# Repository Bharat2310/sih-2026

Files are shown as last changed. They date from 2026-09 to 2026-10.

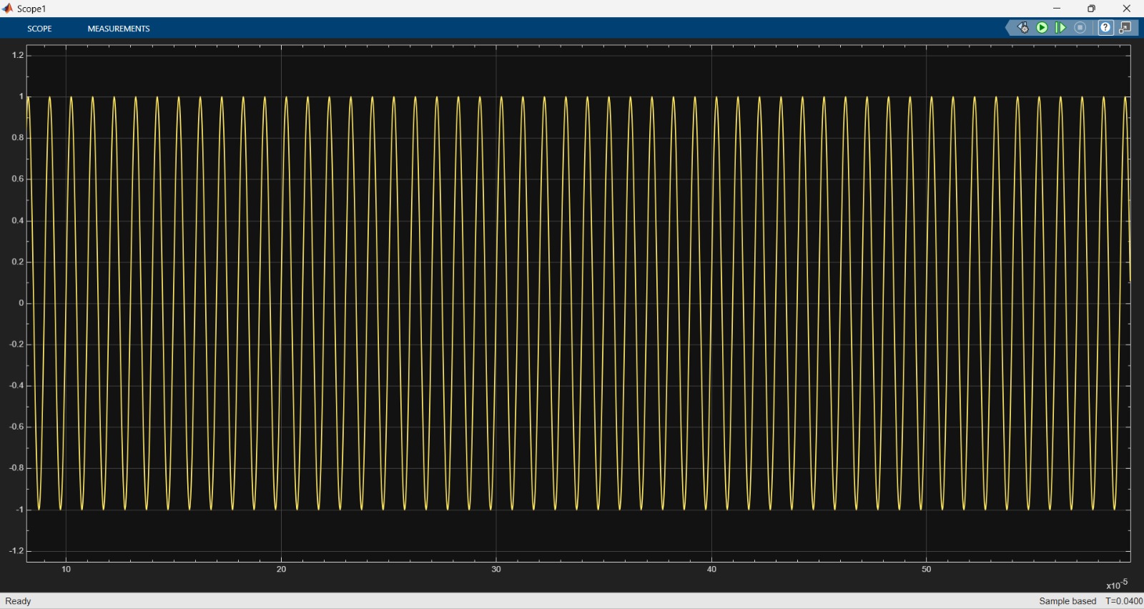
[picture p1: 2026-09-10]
assets/screenshots/mode1_geometricsweep_final.jpeg

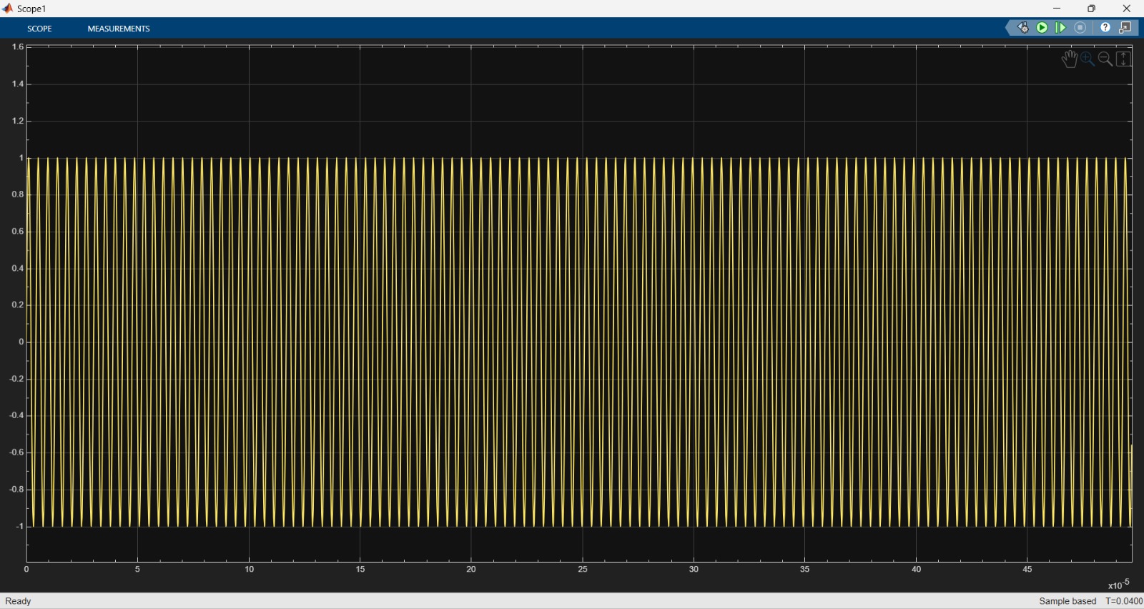
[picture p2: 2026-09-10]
assets/screenshots/mode1_geometricsweep_raw.jpeg

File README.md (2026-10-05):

# Adaptive Underwater Sonar Transmitter for AUVs

## 1. Project Information

- **Project Title:** Adaptive Software-Defined Sonar Transmitter for AUVs
- **PS ID:** 26058
- **PS Title:** Development of a Low-Power, Real-Time Adaptive Software-Defined Sonar Transmitter Payload for Autonomous Underwater Vehicles (AUVs)
- **Category:** Hardware
- **Theme:** Robotics and Drones

## 2. Problem Statement

Fixed-frequency sonar transmitters used in Autonomous Underwater Vehicles (AUVs) perform poorly when water conditions change. High turbidity, varying depth and temperature gradients all affect how sound propagates underwater, causing loss of resolution, weak returns, or complete signal degradation. A sonar system tuned for clear, shallow water fails in turbid or deep-water conditions, and vice versa,  there is no single fixed frequency/pulse configuration that works well everywhere.

## 3. Proposed Solution

We propose a **Software-Defined Sonar (SDS)** transmitter that adapts its waveform in real time based on sensed water conditions, instead of using a single fixed frequency.

The system continuously reads **turbidity**, **depth**, and **temperature** via ADC channels (mapped from potentiometer inputs at the current prototype stage) and uses this data to dynamically determine the most suitable suitable transmission configuration and parameters.

**ADAPTIVE WAVEFORM AND PARAMETER SELECTION**

- **Center frequency** (500 kHz / 250 kHz / 100 kHz) based on turbidity band — turbidity limits the base frequency band to prevent signal scattering
- **Pulse width (T_pulse)** (1 ms / 10 ms / 50 ms) based on depth band — depth dictates total pulse duration for deeper energy penetration
- **Modulation type** — automatically decided by the Mod_Select Decision Block, not manually selected:
         1. heavy silt (turbidity_voltage > 2.4V) forces Barker-13 phase-coded pulse 
         2. deep water (depth_m > 30) forces Geometric Sweep (Mode 1)
         3. standard conditions default to LFM Chirp (Mode 0)
- **Sound velocity correction** using the Mackenzie (1981) formula, recalculated continuously from real-time temperature and fed directly into bandwidth correction every cycle
- **Bandwidth** dynamically compensated to maintain a target 2 cm range resolution (dR_target) across the operating frequency bands, eliminating the need for manual reconfiguration even at the 100 kHz operating point.

**DIGITAL WAVEFORM GENERATION AND LOW POWER TRANSMISSION**

The selected waveform is synthesized digitally by the ESP32. During the 5 ms TX window, the CPU computes a 100-sample waveform array corresponding to the required modulation, frequency, bandwidth and pulse duration.
The waveform then passes through mode-dependent digital windowing:
1. Blackman window for LFM chirps and geometric sweeps to control sidelobes and reduce spectral leakage
2. Rectangular/light Tukey window for Barker-13 phase-coded pulses, where preserving the individual phase-coded chips is important.

Once the waveform is prepared, the ESP32 arms a hardware timer and DMA transfer. The DMA autonomously transfers the 100 samples from RAM to the DAC at a 200 kHz sample rate, corresponding to a 5 μs Zero-Order Hold (ZOH) interval. This allows the CPU to immediately enter Light Sleep instead of continuously driving the DAC in software.
When the DMA transfer finishes, a hardware interrupt wakes the CPU briefly. The CPU shuts down the DAC to prevent unnecessary static power consumption and then returns to sleep during the remaining LISTEN period.
This creates a time-shared TX/LISTEN cycle, allowing the same transducer path to be used for transmission and reception without simultaneous TX/RX conflict.

**ANALOG SIGNAL CONDITIONING AND POWER DELIVERY**

After digital synthesis and DAC conversion, the waveform becomes a low-voltage (~3.3 V) analog signal. This signal is then processed by analog front end to clean, amplify, and efficiently couple it to the piezoelectric sonar transducer.

Analog chain: 
1. Signal Routing: CD4051 Analog MUX
The CD4051 MUX routes the waveform to one of three dedicated Clear, Murky, or Muddy filter paths based on the environmental condition provided by the ESP32.
2. Signal Conditioning: LT1058 Filter
The selected path uses an LT1058 Sallen-Key 2nd-order Butterworth low-pass filter with a condition-specific cutoff frequency. It removes unwanted high-frequency switching noise and harmonics, producing a cleaner ~3.3 V waveform.
3. Power Amplification: LM318N + Class-AB Stage
The filtered signal is amplified using an LM318N driver with a 7.2× feedback gain, followed by a Class-AB BD139/BD140 push-pull stage powered from 18 V rails. This provides the high-voltage, high-current drive required by the transducer, targeting approximately 24 Vpp output.
4. Impedance Matching: LC Network
Since the piezoelectric transducer behaves predominantly as a capacitive load, the LC network uses an inductive component to compensate for its capacitive reactance, improve electrical resonance, and enable more efficient power transfer.
5. Acoustic Transmission: Piezoelectric Transducer
The matched high-voltage waveform is applied to the piezoelectric transducer, which converts the electrical excitation into mechanical vibration and generates the acoustic sonar pulse in water.

This completes the transmitter-side signal chain, with the transducer converting the conditioned electrical waveform into the acoustic sonar pulse for underwater transmission.

## 4. Key Features

- **Real-Time Environmental Adaptation:** Dynamically adapts waveform parameters using turbidity, depth, and temperature.
- **Adaptive 100–500 kHz Operation:** Shifts frequency according to turbidity to reduce scattering.
- **Consistent 2 cm Resolution:** Dynamically compensates bandwidth across operating frequencies.
- **3-Mode Waveform Selection:** Automatically switches between LFM Chirp, Geometric Sweep, and Barker-13 Phase Coding.
- **Temperature-Based Correction:** Continuously calculates acoustic velocity for accurate bandwidth control.
- **Dual-Stage Signal Conditioning:** Combines digital windowing with dedicated analog filtering to reduce sidelobes, noise, and harmonics.
- **DMA-Based Low-Power Operation:** Uses hardware-timed DMA waveform output with a 5 ms TX / 15 ms LISTEN cycle.
- **Impedance-Matched Transducer Drive:** Uses amplification and LC matching for efficient power transfer to the piezoelectric transducer.

## 5. Technology Stack

- **Simulation / Signal Design:** MATLAB R2026a (Simulink, DSP System Toolbox), LTSpice 
- **Embedded Firmware:** ESP32 (C, hardware timers, ISR-driven waveform synthesis, DMA)
- **DAC (Phase 2 hardware):** MCP4921 (SPI)
- **Analog Front End:** CD4051 analog MUX, LT1058 Sallen-Key active filters, LM318N / Class-AB power amplifier, LC impedance matching network
- **Version Control:** Git / GitHub

## 6. Architecture

The system follows an adaptive digital-to-analog signal chain in which environmental inputs determine the transmission frequency, pulse duration, sound-velocity correction, and modulation mode. 
```
Turbidity ADC ─┐
Depth ADC ─────┼──> Decision Logic + Mod_Select Decision Block
Temperature ───┘                    │
                                    ▼
                 Center Freq, T_pulse, Sound Velocity,
                         Bandwidth, Mode (0/1/2)
                                    │
                                    ▼
                       Modulation Selector
                  ┌─────────────────────────────┐
                  │ Mode 0: LFM Chirp           │
                  │ Mode 1: Geometric Sweep     │
                  │ Mode 2: Barker-13           │
                  └─────────────────────────────┘
                                    │
                                    ▼
                       Conditional Windowing
                       (Blackman / Tukey)
                                    │
                                    ▼
                       TX/LISTEN Pulse Gating
                         (0.02 s, 25% duty)
                                    │
                                    ▼
                        Buffer (100) → Unbuffer
                                    │
                                    ▼
                         ZOH (5 μs / 200 kHz)
                                    │
                                    ▼
                                  DAC
                                    │
                                    ▼
                         3.3 V Analog Signal
                                    │
                                    ▼
                         CD4051 Analog MUX
                                    │
                                    ▼
                      Sallen-Key Active Filter
                                    │
                                    ▼
                    LM318N + Class-AB Amplifier
                              (~24 Vpp)
                                    │
                                    ▼
                       LC Impedance Matching
                                    │
                                    ▼
                      Piezoelectric Transducer
```

## 7. Repository Structure

```
sih-2026/
├── README.md
├── submission/
│   ├── PRESENTATION.md      # link to final PPT
│   └── DEMO.md              # link to prototype demo video
├── src/
│   ├── simulink/
│   │   └── before_dac_model.slx     # digital pipeline (Decision Logic -> ... -> ZOH -> DAC)
│   ├── esp32-firmware/
│   │   └── esp32-firmware.ino       # ESP32 firmware (tested build)
│   └── ltspice/
│       ├── after_dac_model.asc      # analog front-end circuit (after DAC)
│       └── working_analog.asc       # working analog reference circuit
├── docs/
│   └── architecture.md
├── assets/
│   └── screenshots/
        ├── after_dac_schematic.jpeg
│       ├── after_dac_waveform.jpeg
│       ├── before_dac_full_pipeline.png
│       ├── decision_logic.jpeg
│       ├── mod_select_decision.jpeg
│       ├── modulation_selector.jpeg
│       ├── mode0_lfm_final.jpeg
│       ├── mode0_lfm_raw.jpeg
│       ├── mode1_geometricalsweep_final.jpeg
│       ├── mode1_geometricalsweep_raw.jpeg
│       ├── mode2_phasecoded_final.jpeg
│       └── mode2_phasecoded_raw.jpeg
│       ├── future_scope_schematic.jpeg
│       └── README.md
├── .gitignore
└── LICENSE
```

## 8. Final Presentation

[View the Final Presentation](submission/PRESENTATION.md)

## 9. Demo Video

[View the Prototype Demo](submission/DEMO.md)

## 10. Screenshots / Prototype Photos

Simulink model screenshots, waveform captures, decision-logic results and analog front-end/prototype images are available in: [assets/screenshots/README.md](assets/screenshots/README.md) 

## 11. Installation

Clone the repository and install the required dependencies:
```
bash
git clone https://github.com/Bharat2310/sih-2026.git
cd sih-2026
```

Prerequisites
1. MATLAB R2026a with Simulink and DSP System Toolbox
2. LTspice
3. Arduino IDE or PlatformIO for ESP32 firmware

## 12. Run

- **Before-DAC Simulink model:** Open `src/simulink/before_dac_model.slx` in MATLAB R2026a and run. Remember to redefine the Blackman window variable in the Command Window after every MATLAB restart:
  ```matlab
  N=100; n=(0:N-1)'; w=0.42-0.5*cos(2*pi*n/(N-1))+0.08*cos(4*pi*n/(N-1));
  ```
- **After-DAC analog front-end model:** Open `src/ltspice/after_dac_model.asc` in LTSpice and run.
- **ESP32 firmware:** Open `src/esp32-firmware/esp32-firmware.ino` in Arduino IDE or PlatformIO, select the appropriate ESP32 board and port then compile and uplaod.
  
## 13. Future Scope

- **Higher-Rate ZOH:** Increase the ZOH sample rate from 200 kHz to ≥1.25 MHz to support the 500 kHz operating band without Nyquist violation
- **Ping-Pong Buffering:** Dual-buffer DMA scheme so the CPU synthesizes the next 100-sample frame while DMA transmits the current one, minimizing CPU active time with zero inter-frame latency/jitter (trade-off: doubles RAM footprint). Planned refinement: hardware-level automatic buffer-pointer swap on DMA interrupt.
- **Fixed-Point DSP:** Replace floating-point calculations with Q15 arithmetic and SRAM lookup tables for faster, low-overhead waveform generation.
- **ADC Hysteresis & Deadbanding (EMA filtering):** Smooths turbidity/temperature ADC reads so the system reacts to real environmental trends instead of chattering between modes around hard thresholds (e.g. 2.4V turbidity), at the cost of slight reaction lag. Planned refinement: bit-shifting EMA calculations instead of division to remove CPU overhead.
- **Dynamic Voltage Scaling:** Dynamically adjust the amplifier supply from approximately 9 V to 24 V according to environmental conditions, with up to 40% projected battery-life improvement.
- **High-Slew Analog Drive:** Use high-slew-rate op-amps with appropriate windowing to reliably support phase-coded waveforms such as Barker-13.

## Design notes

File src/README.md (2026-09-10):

```
src/
├── simulink/
│   ├── before_dac_model.slx   # digital chirp pipeline (before DAC)
│   └── .gitkeep
├── esp32-firmware/
│   ├── esp32-firmware.ino     # ESP32 firmware (tested build)
│   └── .gitkeep
└── ltspice/
    ├── after_dac_model.asc    # analog front-end circuit (after DAC)
    └── working_analog.asc     # working analog reference circuit
```

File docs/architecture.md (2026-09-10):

# Adaptive Software-Defined Sonar Transmitter

## 1. Overview

The transmitter adapts its waveform in real time based on sensed water conditions (turbidity, depth, temperature) instead of relying on a single fixed frequency/pulse configuration. The architecture is split into two halves that map directly onto the two Simulink models in this repo:

- **Digital pipeline (pre-DAC)** — `src/simulink/before_dac_model.slx`: sensing → decision logic → waveform synthesis → windowing → buffering → DAC.
- **Analog front end (post-DAC)** — `src/ltspice/after_dac_model.asc`: DAC output → filtering → amplification → impedance matching → transducer.

The ESP32 (`src/esp32-firmware/`) is the bridge between the two: it runs the decision logic and digital synthesis in firmware, then drives the analog chain via the DAC and MUX control lines.

## 2. Full Signal Chain

```
Turbidity ADC ─┐
Depth ADC ─────┼──> Decision Logic + Mod_Select Decision Block
Temperature ───┘                    │
                                     ▼
                  Center Freq, T_pulse, Sound Velocity,
                          Bandwidth, Mode (0/1/2)
                                     │
                                     ▼
                        Modulation Selector
                   ┌─────────────────────────────┐
                   │ Mode 0: LFM Chirp            │
                   │ Mode 1: Geometric Sweep       │
                   │ Mode 2: Barker-13             │
                   └─────────────────────────────┘
                                     │
                                     ▼
                        Conditional Windowing
                        (Blackman / Tukey)
                                     │
                                     ▼
                        TX/LISTEN Pulse Gating
                          (0.02 s cycle, 25% duty)
                                     │
                                     ▼
                         Buffer (100) → Unbuffer
                                     │
                                     ▼
                          ZOH (5 µs / 200 kHz)
                                     │
                                     ▼
                                   DAC
                                     │
                                     ▼
                          3.3 V Analog Signal
                                     │
                                     ▼
                          CD4051 Analog MUX
                                     │
                                     ▼
                       Sallen-Key Active Filter
                                     │
                                     ▼
                     LM318M + Class-AB Amplifier
                               (~24 Vpp)
                                     │
                                     ▼
                        LC Impedance Matching
                                     │
                                     ▼
                       Piezoelectric Transducer
```

## 3. Digital Pipeline (Pre-DAC)

**Model:** `src/simulink/before_dac_model.slx`

### 3.1 Sensing
Turbidity, depth, and temperature are read via ADC channels (currently mapped from potentiometer inputs at the prototype stage).

### 3.2 Decision Logic + Mod_Select
Environmental readings are converted into transmission parameters:

| Input | Drives | Effect |
|---|---|---|
| Turbidity | Center frequency band (500 / 250 / 100 kHz) | Limits base frequency to prevent signal scattering |
| Depth | Pulse width T_pulse (1 / 10 / 50 ms) | Longer pulses for deeper energy penetration |
| Temperature | Sound velocity (Mackenzie, 1981) | Recalculated continuously and fed into bandwidth correction every cycle |

The **Mod_Select Decision Block** automatically chooses the modulation mode — not manually selected:
1. Turbidity voltage > 2.4 V → **Mode 2: Barker-13** phase-coded pulse (heavy silt)
2. Depth > 30 m → **Mode 1: Geometric Sweep** (deep water)
3. Otherwise → **Mode 0: LFM Chirp** (standard conditions)

Bandwidth is dynamically compensated to hold a target **2 cm range resolution (dR_target)** across all operating frequency bands, including at 100 kHz.

### 3.3 Digital Waveform Synthesis
During the 5 ms TX window, the ESP32 computes a 100-sample waveform array for the selected modulation, frequency, bandwidth, and pulse duration.

### 3.4 Conditional Windowing
- **Blackman window** — LFM chirps and geometric sweeps, to control sidelobes and reduce spectral leakage.
- **Rectangular / light Tukey window** — Barker-13 pulses, to preserve individual phase-coded chips.

### 3.5 TX/LISTEN Gating, Buffering, ZOH, DAC
- Pulse gating enforces a 0.02 s cycle at 25% duty (5 ms TX / 15 ms LISTEN).
- The 100-sample buffer is unbuffered and output through a Zero-Order Hold at 200 kHz (5 µs interval) via hardware-timed DMA.
- DMA transfers samples from RAM to the DAC autonomously, letting the CPU enter Light Sleep during transmission and wake only on the DMA-finish interrupt to shut down the DAC before sleeping through the remainder of LISTEN.

## 4. Analog Front End (Post-DAC) 

**Model:** `src/ltspice/before_dac_model.asc` 

| Stage | Component | Function |
|---|---|---|
| Signal routing | CD4051 Analog MUX | Routes the waveform to one of three condition-specific paths — Clear / Murky / Muddy |
| Signal conditioning | LT1058 Sallen-Key filter | 2nd-order Butterworth low-pass, condition-specific cutoff, removes switching noise/harmonics |
| Power amplification | LM318M + Class-AB (BD139/BD140) | 7.2× feedback gain driver + push-pull stage on 18 V rails → ~24 Vpp output |
| Impedance matching | LC network | Compensates the transducer's capacitive reactance for efficient power transfer |
| Acoustic transmission | Piezoelectric transducer | Converts the conditioned electrical waveform into the acoustic sonar pulse |

## 5. Key Architectural Features
1. **Real-Time Environmental Adaptation:** Turbidity, depth, and temperature directly influence transmission parameters.
2. **Adaptive Frequency Selection:** Operating frequency shifts between 100 kHz, 250 kHz, and 500 kHz according to turbidity.
3. **Adaptive Pulse Duration:** Pulse duration changes between 1 ms, 10 ms, and 50 ms according to depth.
4. **Dynamic Bandwidth Compensation:** Temperature-based sound velocity correction dynamically determines the required bandwidth.
5. **2 cm Target Resolution:** Bandwidth is calculated using the acoustic range-resolution relationship.
6. **Three Modulation Modes:** LFM Chirp, Geometric Sweep, and Barker-13 Phase Coding.
7. **Digital + Analog Signal Conditioning:** Digital windowing is followed by analog filtering.
8. **TX/LISTEN Operation:** A 5 ms TX window followed by a 15 ms LISTEN window enables time-shared sonar operation.
9. **DMA-Compatible Waveform Streaming:** Buffered waveform generation reduces continuous CPU involvement during transmission.
10. **Efficient Transducer Drive:** Power amplification and LC impedance matching improve energy transfer to the piezoelectric transducer.

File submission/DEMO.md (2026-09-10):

# Demo Video

The prototype demonstration video for Project Poseidon is available at the link below.

## Demo Video Link

[Watch the Prototype Demo](https://drive.google.com/drive/folders/1Pm32NLZ3pSUcfD95rD-MbYwJ-gllIJSA)

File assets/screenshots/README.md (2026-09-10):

## Screenshots

Project development and simulation results are documented through the following screenshots.

### Before-DAC Simulation — Team A

* `before_dac_full_pipeline.png` — Complete Simulink transmitter pipeline before DAC.
* `decision_logic.jpeg` — Environmental parameter-based decision logic.
* `mod_select_decision.jpeg` — Modulation mode selection logic.
* `modulation_selector.jpeg` — Selection between LFM, Geometric Sweep, and Phase-Coded modes.
* `mode_0_lfm_raw.jpeg` — Raw LFM chirp waveform.
* `mode_0_lfm_final.jpeg` — Windowed LFM chirp output.
* `mode_1_geometricsweep_raw.jpeg` — Raw geometric sweep waveform.
* `mode_1_geometricsweep_final.jpeg` — Windowed geometric sweep output.
* `mode_2_phasecoded_raw.jpeg` — Raw Barker-13 phase-coded waveform.
* `mode_2_phasecoded_final.jpeg` — Windowed phase-coded output.

### After-DAC Simulation — Team B

* `after_dac_schematic.jpeg` — Analog signal-conditioning and amplification stage after DAC.
* `after_dac_waveform.jpeg` — Resulting waveform after the analog front-end.

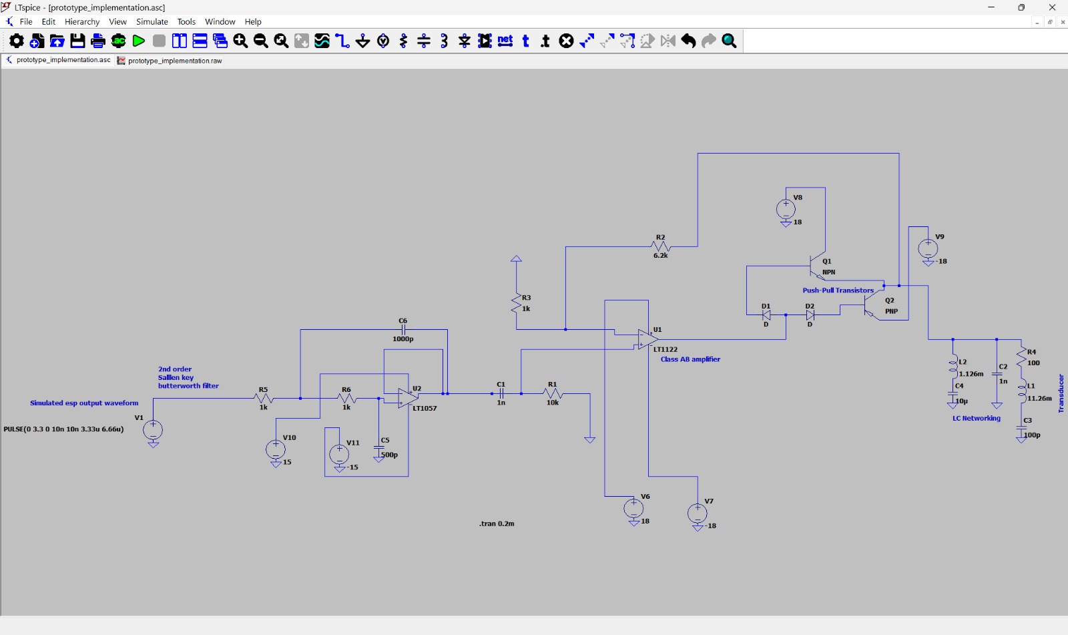
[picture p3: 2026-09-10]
assets/screenshots/future_scope_schematic.jpeg

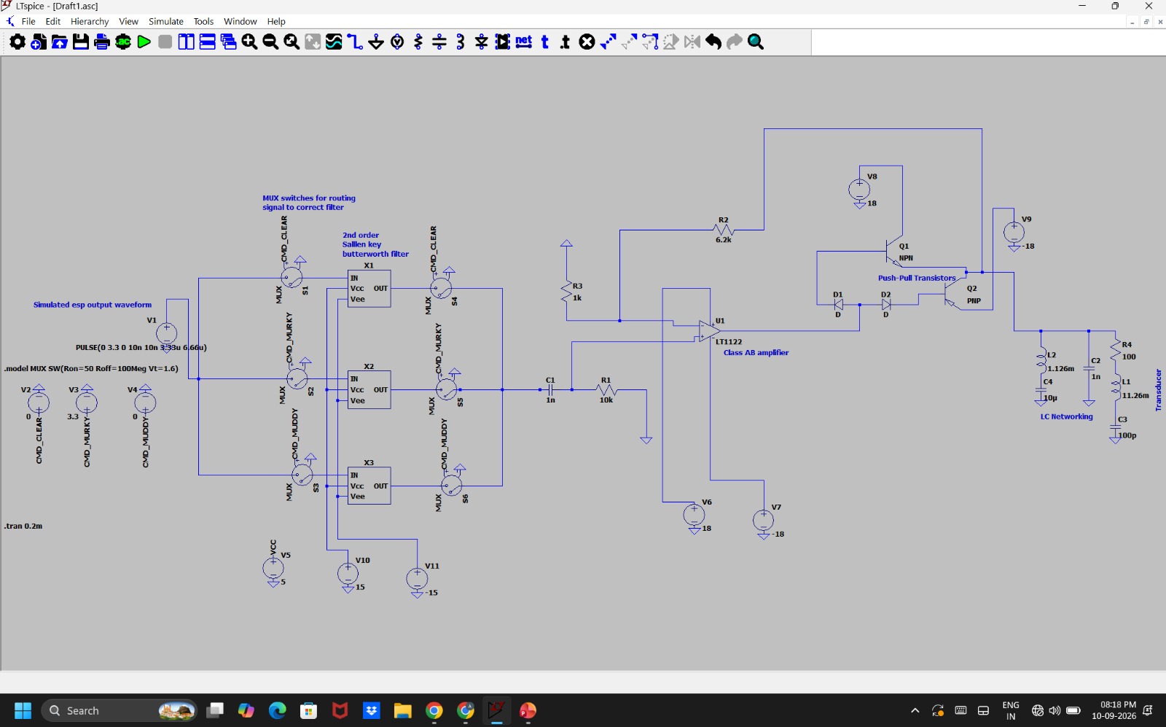
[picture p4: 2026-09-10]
assets/screenshots/after_dac_schematic.jpeg

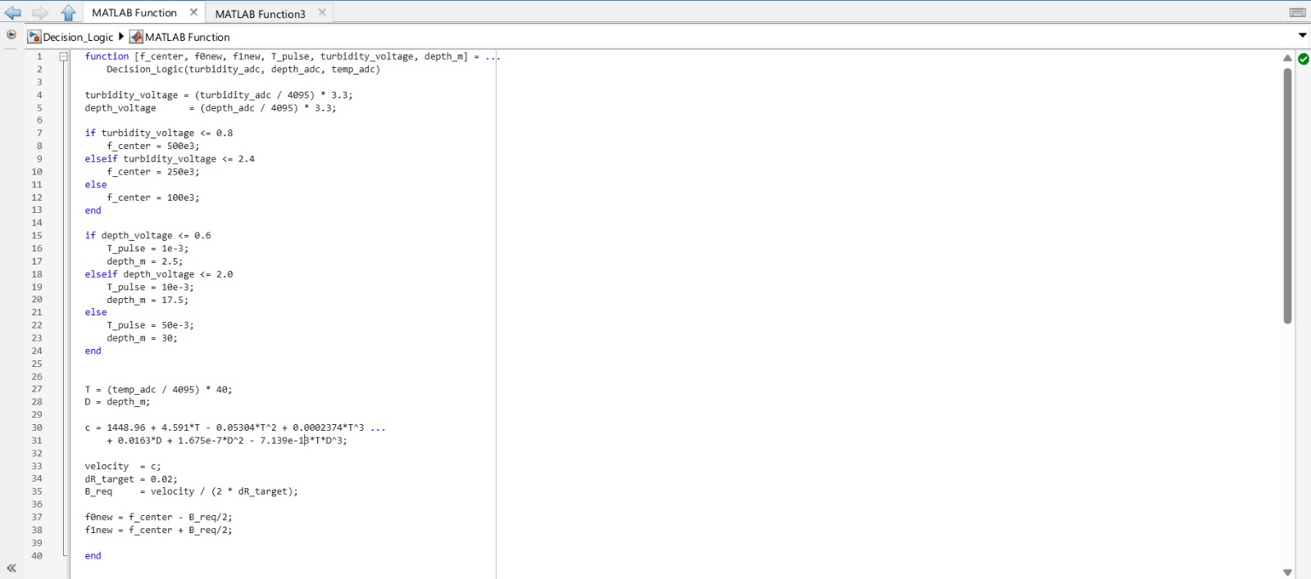
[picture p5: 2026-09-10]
assets/screenshots/decision_logic.jpeg

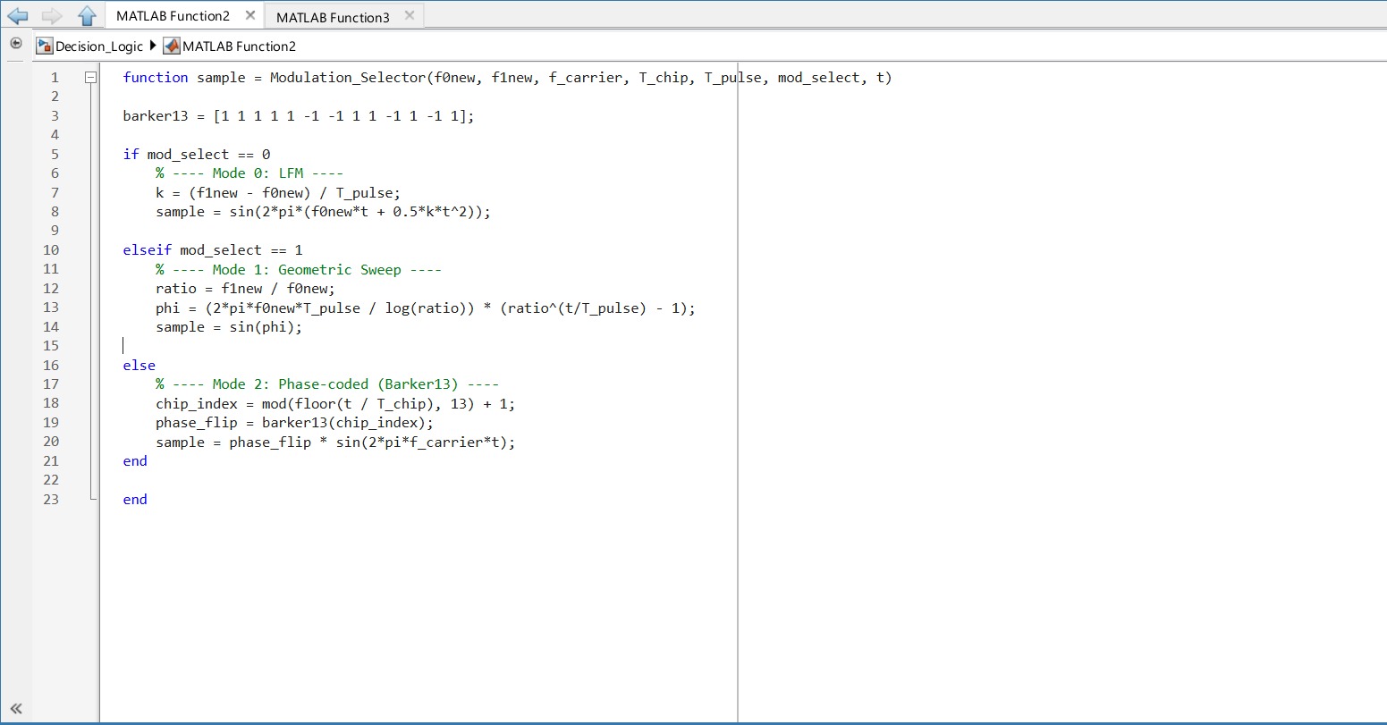
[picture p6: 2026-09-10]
assets/screenshots/modulation_selector.jpeg

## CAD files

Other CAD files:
assets/screenshots/Sonar_Pod_only.step
assets/screenshots/Sonar_Pod_with_hull_ref.step

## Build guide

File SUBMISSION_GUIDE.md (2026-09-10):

# SIH 2026 Submission Guide

Use this checklist before sharing your GitHub repository link.

## Required repository content

- Actual source code is present.
- `README.md` explains the project clearly.
- PS ID and PS title are included.
- Problem statement and proposed solution are explained.
- Key features are listed.
- Technology stack is listed.
- Setup and run instructions work.
- Team members and roles are mentioned.
- Important screenshots or hardware/prototype photos are included.
- Final PPT/presentation is placed in `submission/` whenever practical.
- If the PPT is too large for GitHub, an accessible Google Drive/OneDrive viewer link is added to `submission/PRESENTATION.md`.
- Demo video link is added to `submission/DEMO.md` if available. This is optional.
- Repository is accessible to reviewers.

## Recommended structure

```text
YOUR-SIH-PROJECT/
├── README.md
├── SUBMISSION_GUIDE.md
├── submission/
│   ├── PRESENTATION.md
│   └── DEMO.md
├── src/
├── docs/
├── assets/
│   └── screenshots/
└── ...
```

## Presentation

Upload the final PPT/PPTX to the `submission/` folder when the file size is suitable for GitHub. Use a clear filename such as:

`TeamName_SIH2026_Presentation.pptx`

If the PPT is too large, use Google Drive or OneDrive and put the shareable viewer link in `submission/PRESENTATION.md`.

## Demo video

The demo video is optional. If you have one, add its YouTube/Google Drive link to `submission/DEMO.md` and make sure it is accessible without requesting permission.

## Screenshots / hardware photos

Put important screenshots and prototype photos in `assets/screenshots/`. Include the most useful screens/results rather than random development screenshots.

## Do not upload

- Passwords
- API keys
- Access tokens
- `.env` files containing secrets
- Private credentials
- Other confidential information

## README should answer

1. What problem are you solving?
2. What is your proposed solution?
3. How does it work?
4. Which technologies did you use?
5. How can a reviewer run it?
6. What does the final output look like?
7. What are the important features and expected impact?

## Before submission

Open your repository in a private/incognito browser window or while logged out and verify that the reviewer can access the code, PPT, screenshots, documentation and any submitted links that are supposed to be public.

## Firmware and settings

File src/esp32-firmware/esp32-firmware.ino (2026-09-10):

#include <Arduino.h>
#include <math.h>
#include <SPI.h> // Included for DAC hardware communication

// --- Hardware Input Pins ---
#define PIN_TURB 32
#define PIN_DEPTH 33
#define PIN_TEMP 34

// --- DAC SPI Pins (Standard ESP32 VSPI) ---
#define PIN_DAC_CS 5 // Chip Select for the 8-pin DAC

// --- System Constants ---
const float dR_target = 0.02;          // 2 cm baseline range resolution
const int BUFFER_SIZE = 100;           // N = 100 samples per block
const float SAMPLE_RATE = 200000.0;    // 200 kHz
const float dt = 1.0 / SAMPLE_RATE;    // 5 microseconds (ZOH timestep)

// --- Barker-13 Code ---
const int barker13[13] = {1, 1, 1, 1, 1, -1, -1, 1, 1, -1, 1, -1, 1};

// --- Buffers ---
float wave_buffer[BUFFER_SIZE];

void setup() {
    Serial.begin(115200);
    
    // Initialize SPI bus for the DAC
    SPI.begin(); // Defaults: SCK = GPIO 18, MISO = GPIO 19, MOSI = GPIO 23
    pinMode(PIN_DAC_CS, OUTPUT);
    digitalWrite(PIN_DAC_CS, HIGH); // Unselect DAC initially to prevent floating writes
    
    delay(1000); // Allow ADCs to settle
}

void loop() {
    // ==========================================
    // STEP 1 & 2: INPUTS & DECISION LOGIC
    // ==========================================
    float turb_adc = analogRead(PIN_TURB);
    float depth_adc = analogRead(PIN_DEPTH);
    float temp_adc = analogRead(PIN_TEMP);

    float turbidity_voltage = (turb_adc / 4095.0) * 3.3;
    float depth_m = (depth_adc / 4095.0) * 100.0; 
    float temp = (temp_adc / 4095.0) * 40.0;      

    float f_center = map(turb_adc, 0, 4095, 500000, 100000); 
    float T_pulse = map(depth_adc, 0, 4095, 10, 100) / 1000.0; 

    float velocity = 1449.2 + 4.6 * temp - 0.055 * (temp * temp); 
    float B_req = velocity / (2 * dR_target); 
    float f0new = f_center - (B_req / 2.0);   
    float f1new = f_center + (B_req / 2.0);   

    // ==========================================
    // STEP 3: MOD SELECT DECISION BLOCK
    // ==========================================
    int mod_select;
    if (turbidity_voltage > 2.4) {            
        mod_select = 2; // Heavy silt: Phase-coded (Barker13)
    } else if (depth_m > 30.0) {              
        mod_select = 1; // Deep water: Geometric Sweep
    } else {
        mod_select = 0; // Shallow/Clear: LFM Chirp
    }

    // ==========================================
    // STEP 4, 5 & 6: SYNTHESIS & CONDITIONAL WINDOWING
    // ==========================================
    for (int i = 0; i < BUFFER_SIZE; i++) {
        float cycle_time = i * dt; 
        float sample_val = 0.0;

        if (mod_select == 0) { 
            float k = (f1new - f0new) / T_pulse;
            sample_val = sin(2 * PI * (f0new * cycle_time + (k / 2.0) * cycle_time * cycle_time));
        } 
        else if (mod_select == 1) { 
            float base = f1new / f0new;
            float exponent = cycle_time / T_pulse;
            float freq_inst = f0new * pow(base, exponent);
            sample_val = sin(2 * PI * freq_inst * cycle_time);
        } 
        else if (mod_select == 2) { 
            int chip_index = (int)(cycle_time / (T_pulse / 13.0));
            sample_val = sin(2 * PI * f_center * cycle_time) * barker13[min(chip_index, 12)];
        }

        float window_multiplier = 1.0;

        if (mod_select == 0 || mod_select == 1) {
            window_multiplier = 0.42 
                                - 0.5 * cos(2 * PI * i / (BUFFER_SIZE - 1)) 
                                + 0.08 * cos(4 * PI * i / (BUFFER_SIZE - 1));
        } 
        else if (mod_select == 2) {
            float taper = 0.1; 
            int t_samples = BUFFER_SIZE * taper / 2.0;

            if (i < t_samples) {
                window_multiplier = 0.5 * (1 + cos(PI * ((float)i / t_samples - 1)));
            } else if (i > (BUFFER_SIZE - t_samples)) {
                window_multiplier = 0.5 * (1 + cos(PI * ((float)(i - BUFFER_SIZE) / t_samples + 1)));
            }
        }

        wave_buffer[i] = sample_val * window_multiplier;
    }

    // ==========================================
    // STEP 7: HARDWARE DAC OUTPUT via SPI
    // ==========================================
    for (int i = 0; i < BUFFER_SIZE; i++) {
        // 1. Calculate the 12-bit value (0 to 4095)
        int dac_value = (int)((wave_buffer[i] + 1.0) * 2047.5);
        
        // 2. Hardware fail-safe constraint to prevent bit overflow
        if (dac_value > 4095) dac_value = 4095;
        if (dac_value < 0) dac_value = 0;

        // 3. Construct the 16-bit SPI payload (MCP4921 format)
        // 0x3000 adds the configuration bits: DAC A, Unbuffered, 1x Gain, Active Mode
        uint16_t spi_packet = 0x3000 | dac_value;

        // 4. Send the data to the DAC
        SPI.beginTransaction(SPISettings(20000000, MSBFIRST, SPI_MODE0));
        digitalWrite(PIN_DAC_CS, LOW);   // Select the DAC
        SPI.transfer16(spi_packet);      // Push the 16 bits
        digitalWrite(PIN_DAC_CS, HIGH);  // Deselect the DAC to latch the analog voltage
        SPI.endTransaction();
    }

    // Delay simulating the "Listen" phase before computing the next pulse
    delay(100); 
}

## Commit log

2026-09-10 Add ESP32 firmware (tested build)
2026-09-10 adding ltspice circuits
